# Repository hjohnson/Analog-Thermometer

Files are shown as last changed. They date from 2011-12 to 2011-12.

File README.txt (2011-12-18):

PHYS 320 Final Project: Thermometer. 
Harry Johnson
12/17/11
CC BY/SA 3.0

	These circuits are a paired temperature probe and analog panel meter to display said temperature.
 	
	On the probe side, a 2n3904 NPN transistor is used in saturation, where the Base-Emitter junction is essentially a diode. Silicon diodes in saturation have a fairly linear -2.2mV/ºC temperature coefficient. The forward voltage is also dependent on the collector current of the transistor, so the transistor is immersed in ice water to cool it to 0ºC and a potentiometer is used to calibrate the forward voltage to equal a reference voltage formed by R1 and R2. When this is done, the op amp will output 0 volts when the temperature is 0ºC. Next, a second potentiometer is used to calibrate the gain of the op amp circuit so an increase in 1ºC results in a voltage output increase of 100mV.

	On the panel meter side, a 0-100mA ammeter driven by a standard op amp current source is used to display 0-100ºC.

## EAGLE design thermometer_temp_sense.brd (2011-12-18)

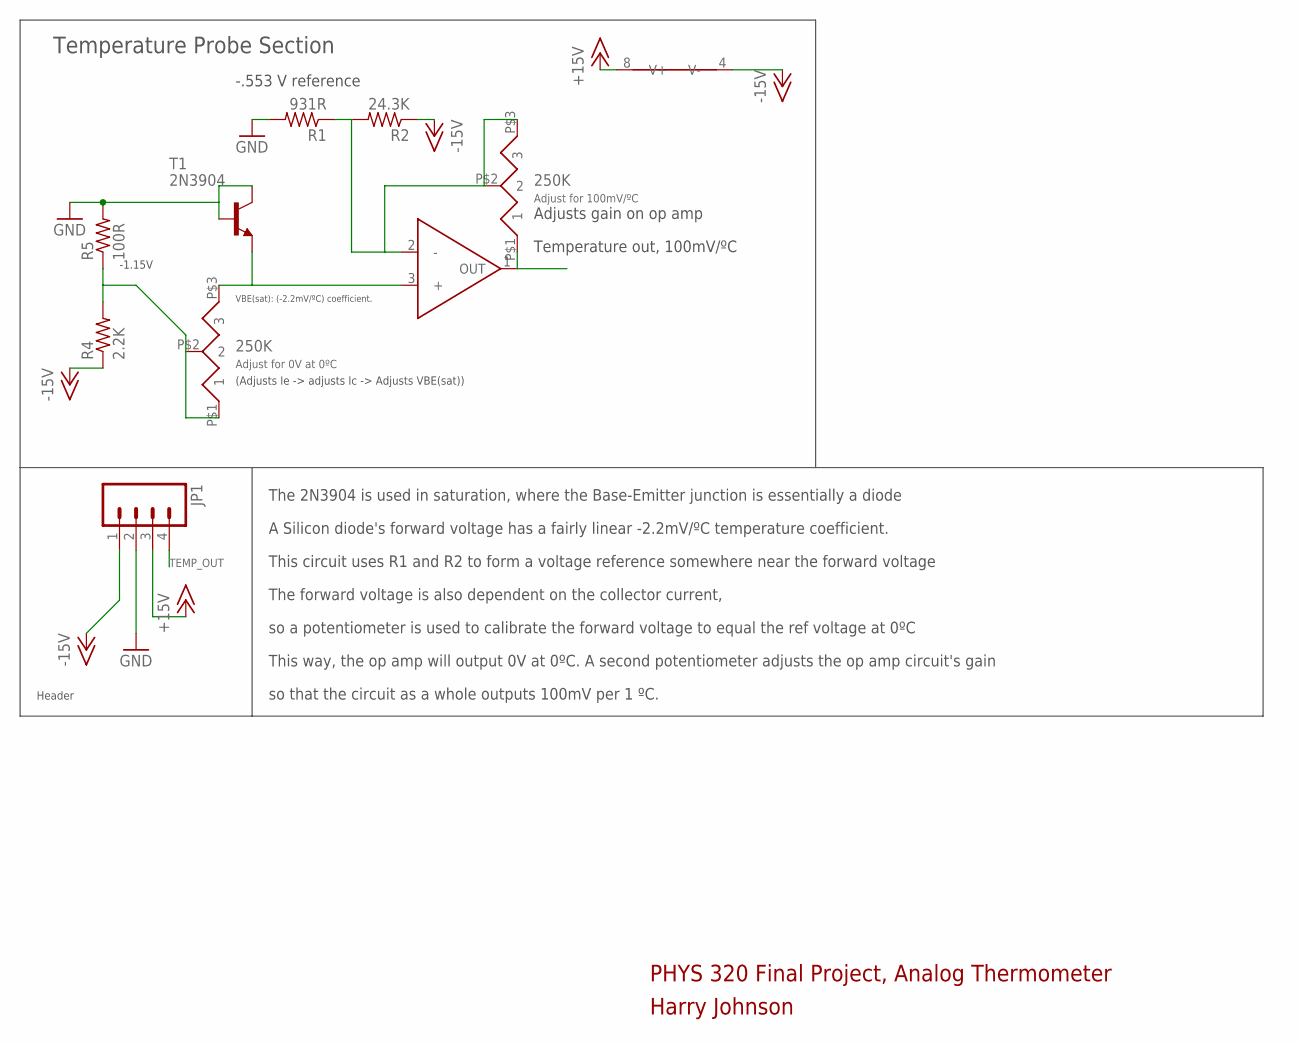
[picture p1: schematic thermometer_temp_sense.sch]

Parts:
JP1: M04PTH; 1X04
R1: 931R; 0207/10
R2: 24.3K; 0207/10
R4: 2.2K; 0207/10
R5: 100R; 0207/10
T1: 2N3904; TO92-EBC-OVAL
U$1: TS522IN; DIL08
U$2, U$3: 250K; PV36Y254C01B00

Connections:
+15V: JP1.3, U$1.8 (V+)
-15V: JP1.1, R2.1, R4.1, U$1.4 (V-)
GND: JP1.2, R1.2, R5.2, T1.B, T1.C
unnamed: R1.1, R2.2, U$1.2 (-), U$3.P$2 (2), U$3.P$3 (3)
unnamed: R4.2, R5.1, U$2.P$1 (1), U$2.P$2 (2)
unnamed: T1.E, U$1.3 (+), U$2.P$3 (3)
TEMP_OUT: JP1.4, U$1.1 (OUT), U$3.P$1 (1)

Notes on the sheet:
250K
Adjust for 100mV/ºC
Adjust for 0V at 0ºC
Temperature out, 100mV/ºC
-.553 V reference
VBE(sat): (-2.2mV/ºC) coefficient.
Temperature Probe Section
(Adjusts Ie -> adjusts Ic -> Adjusts VBE(sat))
-1.15V
Header
Harry Johnson
PHYS 320 Final Project, Analog Thermometer
Adjusts gain on op amp
The 2N3904 is used in saturation, where the Base-Emitter junction is essentially a diode
A Silicon diode's forward voltage has a fairly linear -2.2mV/ºC temperature coefficient.
This circuit uses R1 and R2 to form a voltage reference somewhere near the forward voltage
The forward voltage is also dependent on the collector current,
so a potentiometer is used to calibrate the forward voltage to equal the ref voltage at 0ºC
This way, the op amp will output 0V at 0ºC. A second potentiometer adjusts the op amp circuit's gain
so that the circuit as a whole outputs 100mV per 1 ºC.

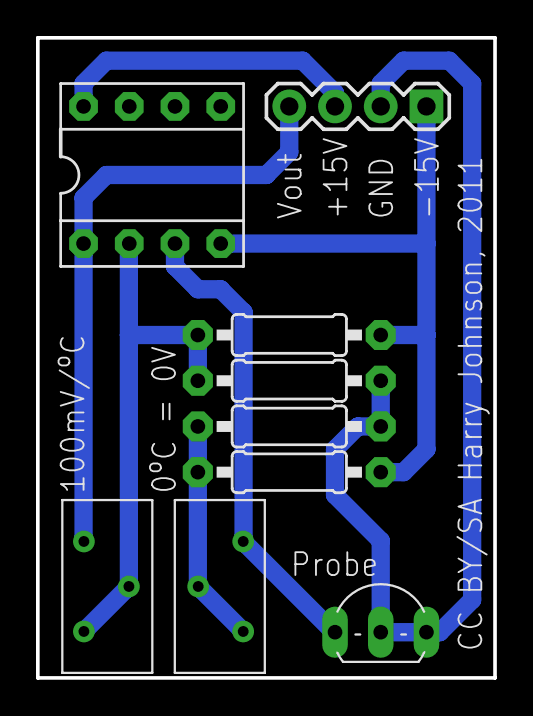
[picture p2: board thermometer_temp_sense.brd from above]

Board: 2 copper layers, 25.4 x 35.6 mm, 9 parts (0 on the bottom side), 7 nets.

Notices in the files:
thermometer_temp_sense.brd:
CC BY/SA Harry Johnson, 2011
